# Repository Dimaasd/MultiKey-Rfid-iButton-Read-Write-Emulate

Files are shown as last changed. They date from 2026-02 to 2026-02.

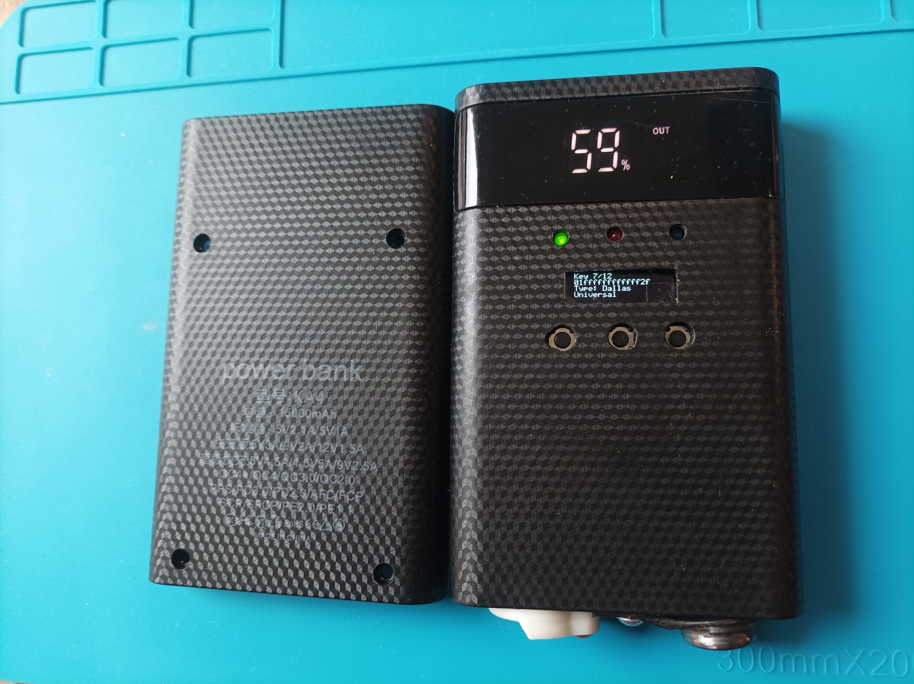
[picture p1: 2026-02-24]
jpg/IMG_20260224_112338.jpg

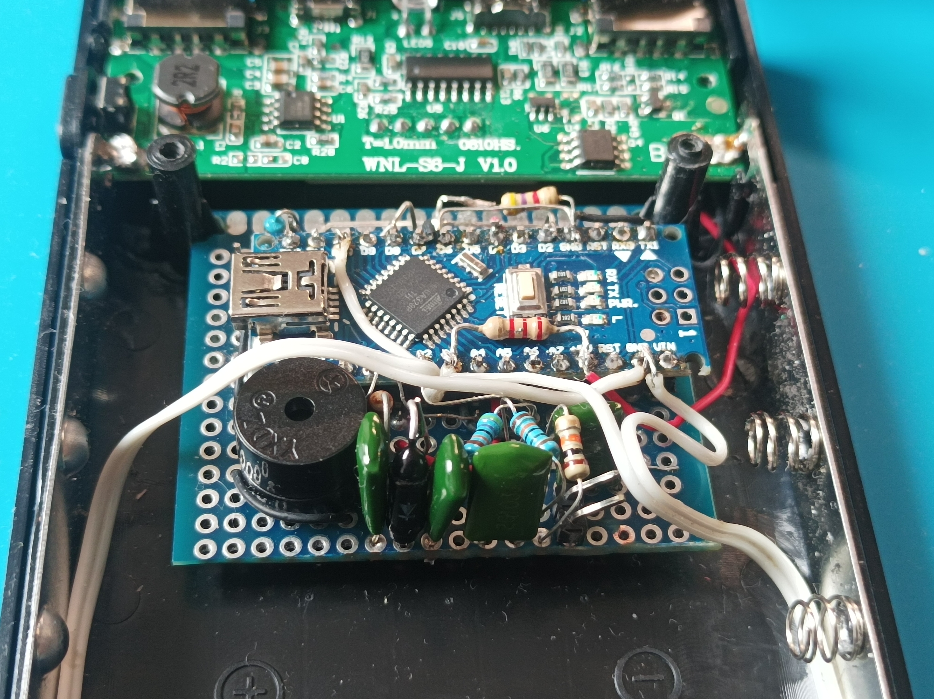
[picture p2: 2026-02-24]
jpg/IMG_20260224_112535.jpg

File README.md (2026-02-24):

# MultiKey-Rfid-iButton-Read-Write-Emulate

Пристрій призначений для читання, копіювання, збереження та емуляції ключів домофонів різних типів.

Він підтримує як контактні ключі Dallas (iButton), так і безконтактні RFID-мітки стандарту EM-Marine 125 кгц

Початковий скетч - це робота [AlexMalov/EasyKeyDublicatorRFID_OLED](https://github.com/AlexMalov/EasyKeyDublicatorRFID_OLED) (т.н. проект "MEXATРОН DIY")
- змінені деякі елементи схеми і коду (запущена емуляція iButton)
- замість енкодера, три кнопки
- видалено виведення інформації в серійний порт (для економії місця в пам'яті в ардуїно)
- дисплей: OLED 128x32 (I2C) хотів поміняти на - 128x64 (I2C), але пам'ять ардуіно обмежена - бібліотеки не влазять
- котушка L1 345 мкГн - замінена на 736 мкГн (провід 0,25 мм, 155 витків, діаметр 20 мм, ширина 2 мм, корпус котушки.stl)
- конденсатор для резенансу С1 4.7нФ - замінений на 2,2нФ
  
Основна проблема добитись резонансу в контурі, 
потріно намотати на котушку більше витків (180 наприклад),
а потім в режимі зчитування (горить зелений діод) замірювати напругу на контрольних точках TP1 і TP2,
відмотуючи по одному витку з котушки контролюємо зміну напруги, 
при досягненні найвищої напруги - фіксуємо край проводу,
У мене зчитує. записує, емулює з 5-6 сантиметрів,
корпус котушки перед 3Д друком розрізав у слайсері на три частини- два борти і центр,
а потім склеював усе разом, борти з гладкою стороною зазташовував в середину, 
щоб при намотці провід не зачипався об зазубрини погрішностей друку,
Використав корпус павербанку, по назві можна знайти на аліекспресі або де інде, 
макетна плата помістилась замість двох акумуляторів 18650, зручно із живлення не подрібно додаткового вимикача,
одне натискання на бокову кнопку павербанку включає плату і заодно подається напруга 5 вольт на ардуіно нано,
сама плата павербанку не переходить в сон від низького зпоживання,
виключається подвійним натисканням на цю ж кнопку.
задня кришка закручується гвинтами.

4x18650 DIY Power Bank Shell 25W Super Fast Charging Case Dual USB Micro Type C Battery Storage Box Case Holder Without Battery

Schematic

🔧 Апаратна частина:

Мікроконтролер: Arduino Nano (ATmega328P),
- Дисплей: OLED 128x32 (I2C)
- Інтерфейс керування: 3 тактові кнопки
- Індикація: RGB-світлодіод + окремий світлодіод
- Звуковий супровід: п'єзодинамік
- Живлення: від USB або зовнішнього джерела

📌 Призначення виводів (Pinout):
- Пін	 - Призначення	   - Опис
- A3	 - iButtonPin	     - Лінія даних iButton
- 7	   - RfidPin	       - Лінія даних Rfid
- 10   - iBtnEmulPin	   - Емуляція iButton
- 8	- R_Led	RGB - червоний
- 2	- G_Led	RGB -  зелений
- 12 - B_Led RGB - синій
- 6	- ACpin	- Вхід аналогового компаратора, замкнутий на gnd
- 3	- speakerPin	- Buzzer П'єзодинамік
- 11	- FreqGen	- Генератор 125 кГц для RFID
- A1	- BTN_MODE	- Кнопка режиму
- A2	- BTN_LEFT	- Кнопка "Лівий"
- A0	- BTN_RIGHT	- Кнопка "Правий"
  
📦 Пам'ять та зберігання:
- EEPROM: зберігає до 42 ключів з назвами

Кожен ключ зберігається як структура KeyData:
- 8 байт - ID ключа
- 16 байт - текстова назва

🗝️ Підтримувані типи ключів:
- Dallas (iButton) - контактні ключі
- Cyfral - контактні
- Metacom - контактні
- TM2004 - контактні
- EM-Marine - безконтактні (RFID 125 кГц)

🎮 Режими роботи (перемикання кнопкою MODE):
- Read (зелений) - режим читання ключів
- Write (червоний) - режим запису на чистий ключ
- BlueMode (синій) - режим емуляції ключа

🕹️ Керування:
- Дія	- Функція
- MODE (коротке натискання)	- Перемикання режимів (Read → Write → BlueMode)
- LEFT/RIGHT	- Перегортання збережених ключів
- MODE (утримання в Read) - 	Збереження поточного ключа в EEPROM
- MODE (утримання в Write) - 	Видалення поточного ключа (з підтвердженням)
- MODE (під час емуляції)	- Зупинка емуляції

🔄 Функціональні можливості:
- Читання ключів
- Автоматичне визначення типу ключа (Dallas, Cyfral, Metacom, EM-Marine) при піднесенні до зчитувача.

- Запис ключів:
- Підтримка різних типів чистих заготовок:
- TM2004
- RW1990-1 / RW1990-2
- TM01
- T5557 (для RFID)

- Емуляція ключів:
- Dallas: використовує бібліотеку OneWireHub для точної емуляції
- EM-Marine: генерація сигналу 125 кГц

- Керування пам'яттю:
- Збереження прочитаних ключів
- Видалення окремих ключів
- Перегляд списку ключів

- Автоматичне визначення дублікатів

🔊 Звукова індикація:
- Старт пристрою - мелодія
- Успішне читання/запис - звуковий сигнал
- Помилка - тривожний сигнал
- Початок/кінець емуляції - спеціальний сигнал
- Видалення ключа - низький звук

💡 Світлодіодна індикація:
- Зелений - режим читання
- Червоний - режим запису
- Синій - режим емуляції RFID-мітки
- Блимання синім - активна емуляція iButton

📟 Дисплей (OLED 128x32) Відображає:
- Поточний режим
- Номер ключа та загальну кількість
- HEX-код ключа (8 байт)
- Тип ключа
- Назву ключа (якщо є)
- Підказки для користувача

📚 Вбудовані універсальні ключі
- Пристрій містить набір універсальних ключів:
- Домофон
- Гараж
- UK-3 Cyfral
- Universal
- Vizit 99%
- Forward
- Cyfral
- Metakom 95%

🛠️ Використані бібліотеки:
- OneWire - робота з шиною 1-Wire
- OneWireSlave - емуляція пристроїв 1-Wire
- OneWireHub - розширена емуляція
- DS2401 - віртуальний пристрій Dallas
- GyverOLED - робота з OLED дисплеєм
- TimerOne - таймер для генерації сигналів
- pitches.h - ноти для звукових сигналів
- EEPROM - робота з внутрішньою пам'яттю

⚙️ Технічні деталі:
- Частота генератора RFID: 125 кГц
- Максимальна кількість ключів: 42
- Антидребезг кнопок: 50 мс
- Таймаут утримання: 1 секунда
- Автоматичне завершення емуляції: 30 секунд

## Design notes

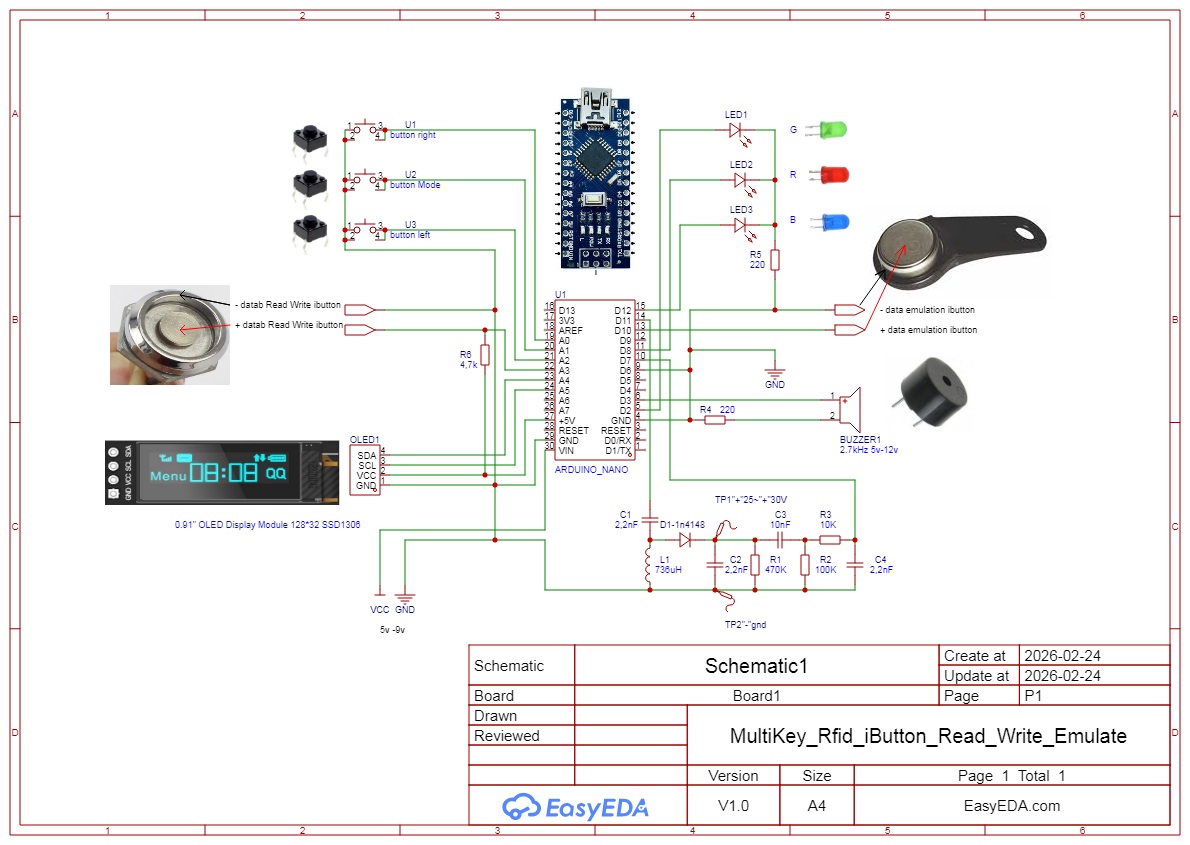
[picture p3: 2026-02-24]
Schematic.jpg

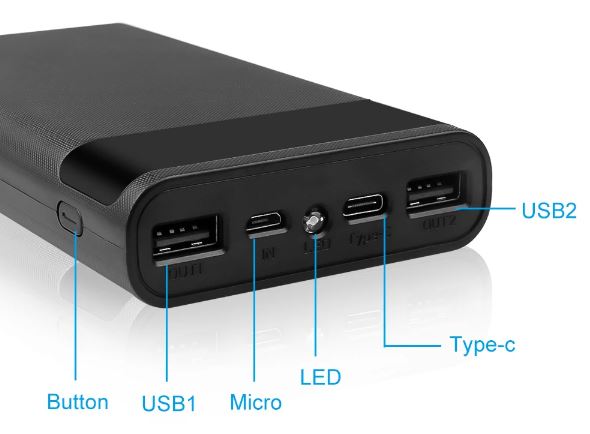
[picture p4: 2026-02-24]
jpg/Box.JPG

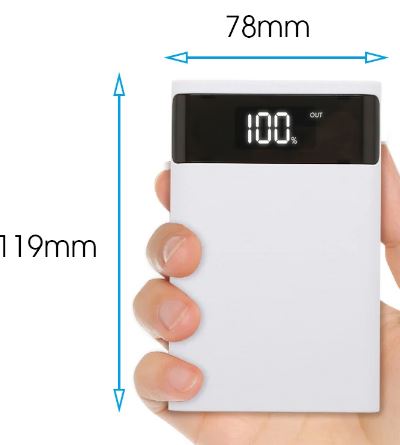
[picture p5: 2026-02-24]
jpg/Box2.JPG

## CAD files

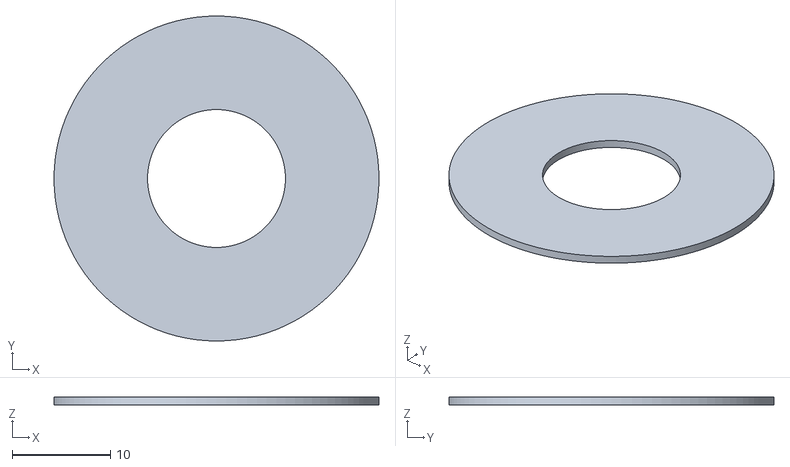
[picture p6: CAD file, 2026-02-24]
stl/борт котушки.stl
33.0 x 33.0 x 0.8

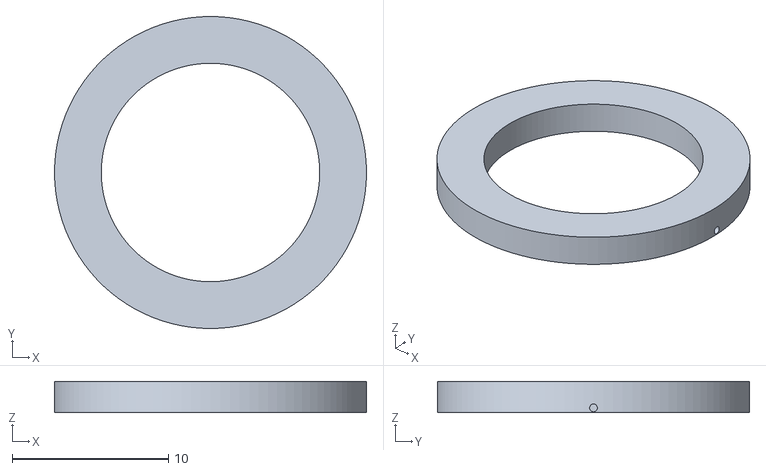
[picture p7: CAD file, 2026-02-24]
stl/центр котушки.stl
20.0 x 20.0 x 2.00

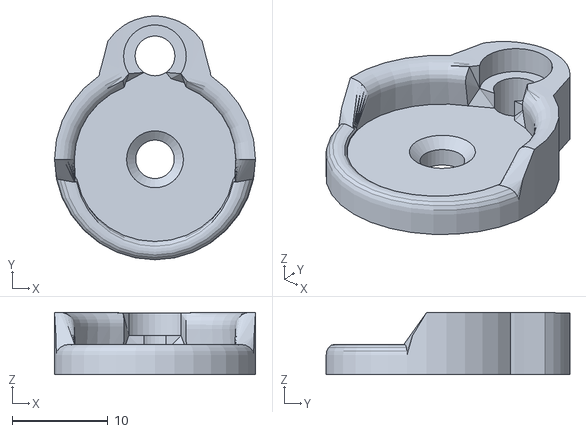
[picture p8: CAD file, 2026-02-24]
stl/ibutton_v1.stl
21.0 x 25.5 x 6.51

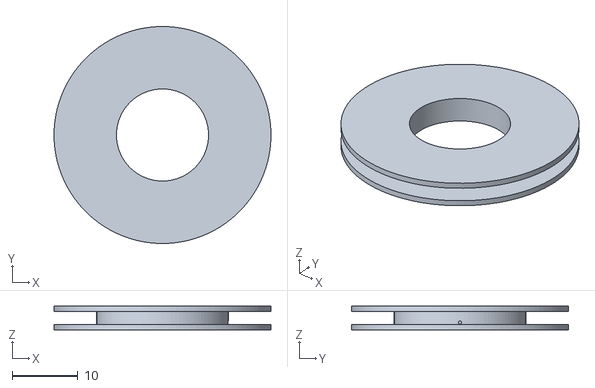
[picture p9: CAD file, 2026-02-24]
stl/корпус котушки.stl
33.0 x 33.0 x 3.60

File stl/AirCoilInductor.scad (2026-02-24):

//this is to build a straight open air coil inductor.

/* [Size] */

diameter = 20;
length = 2.0;
thickness = 3;
segments = 100;

/* [Lip] */

lip_width = 0.8;
lip_offset = 6.5;

/* [Holes] */

hole_upper = "no"; //[yes, no]
hole_lower = "yes"; //[yes, no]
hole_diameter = 0.5;

/* [Hidden] */

$fn = segments;

//build
difference() {
	OuterCoil();
    InnerCoil();
    
    if(hole_upper == "yes") {
        Hole([0, 0, lip_width + length+1 ]);
    }
    
    if(hole_lower == "yes") {
        Hole([0, 0, lip_width+0.3]);
    }
}

//modules
module OuterCoil() {
	union() {
		//base lip
		cylinder (
			h = lip_width, 
			d = lip_offset * 2 + diameter,
			center = false);

		translate ([0, 0, lip_width]) {
			//coil holder
			cylinder (
				h = length, 
				d = diameter,
				center = false);

			translate ([0, 0, length]) {
				//top lip
				cylinder (
					h = lip_width, 
					d = lip_offset * 2 + diameter,
					center = false);
			}	
		}
	}
}

module InnerCoil() {
    translate ([0, 0, -1]) {
        cylinder (
        h = lip_width * 2 + length + 2, 
        d = diameter - thickness * 2,
        center = false);
    }
}

module Hole(pos=[0, 0, 0]) {
    translate(pos) {
        rotate([0, 90, 0]) {
            cylinder (
                h = lip_width * 2 + diameter, 
                d = hole_diameter,
                center = false);
        }
    }
}

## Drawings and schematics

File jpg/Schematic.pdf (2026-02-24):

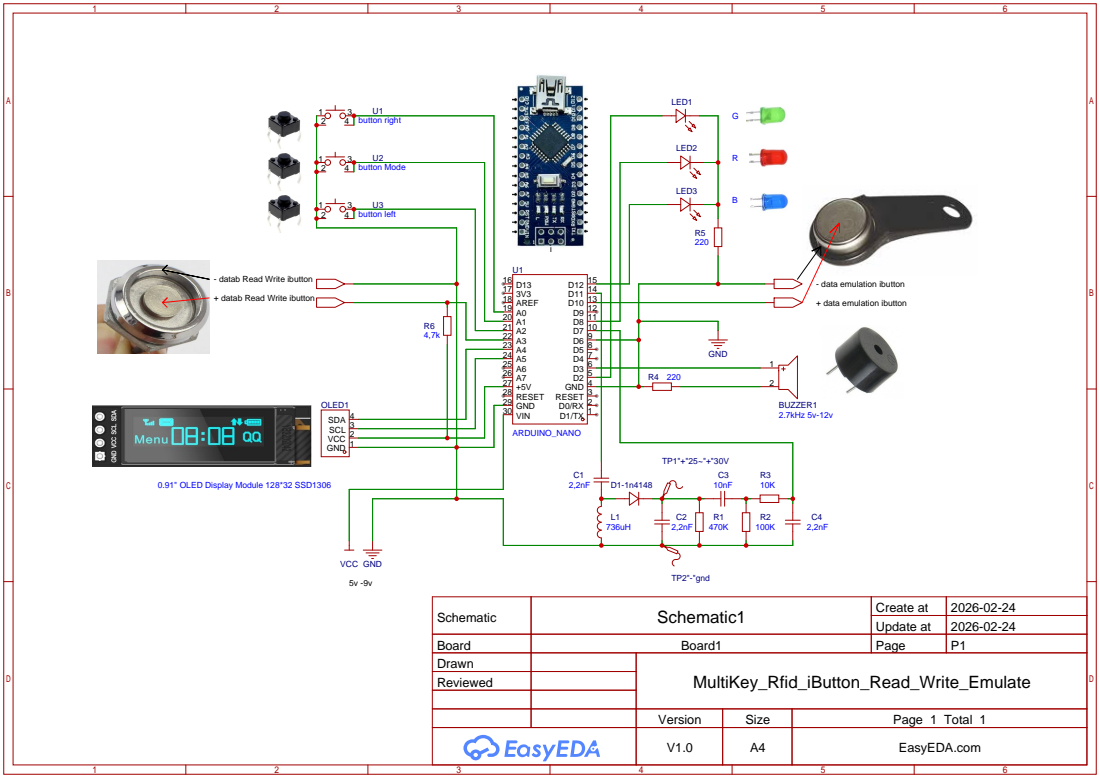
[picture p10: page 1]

+ datab Read Write ibutton

Schematic | Schematic1 | Create at | 2026-02-24

Update at | 2026-02-24

Board | Board1 | Page | P1
Drawn | | MultiKey_Rfid_iButton_Read_Write_Emulate
Reviewed

Version | Size | Page 1 Total 1
V1.0 | A4 | EasyEDA.com

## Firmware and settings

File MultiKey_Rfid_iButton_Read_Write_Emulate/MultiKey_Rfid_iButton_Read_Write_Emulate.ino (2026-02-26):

/*
  Sketch for "MultiKey-Rfid-iButton-Read-Write-Emulate"
  RFID Key Copier with OLED display and 42 keys storage in EEPROM
  Hardware based on Arduino Nano
  v 3.2 fix cyfral bug
  v 3.3 added RFID output in format FF:A9:8A:A1:81:D6:5E:8C: ( id 86 key 1513154234) Type: EM-Marine
  v 3.4 replaced encoder with three buttons control
  v 3.5 Simplified key adding - now keys are added through array with names
  v 3.6 Removed Luse_Led and all Serial outputs except e command for clearing
  v 3.7 Key name displayed in 4th line, key info in EEPROM - in first line
  v 4.0 Added iButton and RFID emulation
  v 4.1 Added key deletion via MODE + LEFT
*/

// Settings
#include <OneWire.h>
#include <OneWireSlave.h>
#include <OneWireHub.h>     // Added for iButton emulation
#include <DS2401.h>         // Added for Dallas emulation
#include "pitches.h"
#include <EEPROM.h>
#include "TimerOne.h"
#include "GyverOLED.h"

//settings
#define rfidUsePWD 0        // key uses password for change
#define rfidPWD 123456      // key password
#define rfidBitRate 2       // RFID exchange speed in kbps

//pins
#define iButtonPin A3      // ibutton data line
#define iBtnEmulPin 10     // emulator ibutton line
#define R_Led 8            // RGB Led
#define G_Led 2
#define B_Led 12
#define ACpin 6            // Input Ain0 of analog comparator 0.1V for EM-Marie 
#define speakerPin 3       // Speaker, buzzer, beeper
#define FreqGen 11         // 125 kHz generator
#define BTN_MODE A1         // Mode switch button read/write
#define BTN_LEFT A2         // "Left" button (previous key)
#define BTN_RIGHT A0       // "Right" button (next key)

OneWire ibutton (iButtonPin);
OneWireSlave iBtnEmul(iBtnEmulPin);       // iButton emulator for BlueMode

// ============ FOR EMULATION ============
auto hub = OneWireHub(iBtnEmulPin);      // Main OneWire hub for iButton emulation
DS2401* currentDS = nullptr;              // Current device for Dallas emulation
bool emulating = false;                   // Is emulation active
// =====================================

byte maxKeyCount;                         // maximum number of keys that fit in EEPROM, but not > 42
byte EEPROM_key_count;                    // number of keys 0..maxKeyCount stored in EEPROM
byte EEPROM_key_index = 0;                // 1..EEPROM_key_count number of the last key written to EEPROM  
byte addr[8];                             // temporary buffer
byte keyID[8];                            // key ID for writing
byte rfidData[5];                         // significant frid em-marine data
byte halfT;                               // half period for metacom

// Button processing variables
unsigned long lastDebounceTime[3] = {0, 0, 0};
unsigned long debounceDelay = 50;
unsigned long holdTimeStart = 0;
unsigned long comboTimeStart = 0;          // Combination start time
bool holdMode = false;
bool comboMode = false;                    // Combination waiting mode
bool lastBtnState[3] = {HIGH, HIGH, HIGH};
bool btnState[3] = {HIGH, HIGH, HIGH};

// ============ SIMPLIFIED KEY ADDING ============
// Structure for storing key with name
struct UniversalKey {
  const char* name;        // Key name for OLED display
  byte data[8];            // Key data
};

  // Array of universal keys with names
UniversalKey universalKeys[] = {
  // Dallas/Metakom/Cyfral keys (start with 0x01)
  {"Univer 1F",              {0x01, 0xFF, 0xFF, 0xFF, 0xFF, 0x1F, 0xFF, 0x00}}, // - 1 Univer 1F
  {"Univer 2F",              {0x01, 0xFF, 0xFF, 0xFF, 0xFF, 0x2F, 0xFF, 0x00}}, // - 2 Univer 2F
//  {"UK-1 Metakom 2003",      {0x01, 0xFF, 0xFF, 0xFF, 0xFF, 0x00, 0x00, 0x9B}}, // - 3 UK-1 Metakom 2003
//  {"UK-2 Vizit",             {0x01, 0xBE, 0x40, 0x11, 0x5A, 0x36, 0x00, 0xE1}}, // - 4 UK-2 Vizit
//  {"UK-3 Cyfral",            {0x01, 0x00, 0x00, 0x00, 0x00, 0x00, 0x00, 0x3D}}, // - 5 UK-3 Cyfral
//  {"Standard Universal",     {0x01, 0xFF, 0xFF, 0xFF, 0xFF, 0xFF, 0xFF, 0x2F}}, // - 6 Standard universal key
//  {"Ordinary",               {0x01, 0xFF, 0xFF, 0xFF, 0xFF, 0xFF, 0xFF, 0x00}}, // - 7 Ordinary
//  {"Old Door Work",          {0x01, 0x00, 0x00, 0x00, 0x00, 0x90, 0x19, 0xFF}}, // - 8 Works great on old intercoms
//  {"Cyfral Metakom 1",       {0x01, 0x53, 0xD4, 0xFE, 0x00, 0x00, 0x7E, 0x88}}, // - 9 Cyfral, Metakom
//  {"Cyfral Metakom 2",       {0x01, 0x53, 0xD4, 0xFE, 0x00, 0x00, 0x7E, 0x00}}, // - 10 Cyfral, Metakom
  {"Metakom 98%",            {0xFF, 0xFF, 0xFF, 0xFF, 0xFF, 0xFF, 0xFF, 0x14}}, // - 11 Opens 98% Metakom and some Cyfral
//  {"Cyfral Filter",          {0x01, 0xFF, 0xFF, 0x01, 0x00, 0x00, 0x00, 0x00}}, // - 12 Cyfral intercoms + filter and protection
//  {"Metakom",                {0x01, 0xFF, 0xFF, 0xFF, 0xFF, 0x00, 0x00, 0x00}}, // - 13 Metakom
  {"Metakom 95%",            {0xFF, 0xFF, 0xFF, 0xFF, 0xFF, 0x00, 0x00, 0xA0}}, // - 14 Metakom 95%
//  {"KeyMan",                 {0x01, 0x00, 0xBE, 0x11, 0xAA, 0x00, 0x00, 0xFB}}, // - 15 KeyMan intercoms
//  {"Vizit KeyMan",           {0x01, 0xBE, 0x40, 0x11, 0x0A, 0x00, 0x00, 0x1D}}, // - 16 tested works Vizit sometimes KeyMan
//  {"Vizit 99%",              {0x01, 0x53, 0xD4, 0xFE, 0x00, 0x00, 0x00, 0x6F}}, // - 17 Vizit intercoms - up to 99%
//  {"Vizit 99% Plus",         {0x01, 0xBE, 0x40, 0x11, 0x5A, 0x36, 0x00, 0x00}}, // - 18 Vizit 99%
//  {"Forward",                {0x01, 0x76, 0xB8, 0x2E, 0x0F, 0x00, 0x00, 0x5C}}, // - 19 Forward intercoms
//  {"Eltis 90%",              {0x01, 0xA9, 0xE4, 0x3C, 0x09, 0x00, 0x00, 0x00}}, // - 20 Eltis intercoms - up to 90%
//  {"Vizit Tested 1",         {0x01, 0xBE, 0x40, 0x11, 0x5A, 0x56, 0x00, 0xBB}}, // - 21 tested works
//  {"Vizit Tested 2",         {0x01, 0xBE, 0x40, 0x11, 0x00, 0x00, 0x00, 0x77}}, // - 22 tested works
  {"Metakom 22",             {0x01, 0xAA, 0x69, 0xC9, 0x36, 0x00, 0x00, 0xE9}}, // Your original Metakom key
//  {"EM-Marine 76",           {0xFF, 0xA9, 0x8A, 0xB8, 0x13, 0x14, 0x8F, 0xB4}}, // - EM-Marine 76
//  {"EM-Marine 42a",          {0xFF, 0xA9, 0x8A, 0xA7, 0x65, 0xBC, 0x16, 0xE6}}, // - EM-Marine 42a
//  {"EM-Marine 42b",          {0xFF, 0xA9, 0x8A, 0xA7, 0x65, 0xB9, 0x3D, 0x9C}}, // - EM-Marine 42b
  {"Garage EM-Marine",       {0xFF, 0x94, 0x60, 0x05, 0xF7, 0xBF, 0x5D, 0x30}}  // Your original Garage EM-Marine key
};

// Number of keys in array
const int UNIVERSAL_KEYS_COUNT = sizeof(universalKeys) / sizeof(UniversalKey);
// ==================================================

enum emRWType {rwUnknown, TM01, RW1990_1, RW1990_2, TM2004, T5557, EM4305};               // blank type
enum emkeyType {keyUnknown, keyDallas, keyTM2004, keyCyfral, keyMetacom, keyEM_Marine};    // original key type  
emkeyType keyType;
enum emMode {md_empty, md_read, md_write, md_blueMode};               // copier operating mode
emMode copierMode = md_empty;

GyverOLED<SSD1306_128x32, OLED_NO_BUFFER> oled; // Using without buffer

//***************** sounds ****************
void Sd_StartOK() {   // sound "Successful startup"
  tone(speakerPin, NOTE_A7); delay(100);
  tone(speakerPin, NOTE_G7); delay(100);
  tone(speakerPin, NOTE_E7); delay(100); 
  tone(speakerPin, NOTE_C7); delay(100);  
  tone(speakerPin, NOTE_D7); delay(100); 
  tone(speakerPin, NOTE_B7); delay(100); 
  tone(speakerPin, NOTE_F7); delay(100); 
  tone(speakerPin, NOTE_C7); delay(100);
  noTone(speakerPin); 
}

void Sd_ReadOK() {  // sound OK
  for (int i=400; i<6000; i=i*1.5) { tone(speakerPin, i); delay(20); }
  noTone(speakerPin);
}

void Sd_WriteStep(){  // sound "next step"
  for (int i=2500; i<6000; i=i*1.5) { tone(speakerPin, i); delay(10); }
  noTone(speakerPin);
}

void Sd_ErrorBeep() {  // sound "ERROR"
  for (int j=0; j <3; j++){
    for (int i=1000; i<2000; i=i*1.1) { tone(speakerPin, i); delay(10); }
    delay(50);
    for (int i=1000; i>500; i=i*1.9) { tone(speakerPin, i); delay(10); }
    delay(50);
  }
  noTone(speakerPin);
}

void Sd_DeleteOK() {  // sound "Deletion successful"
  tone(speakerPin, NOTE_C7); delay(100);
  tone(speakerPin, NOTE_E7); delay(100);
  tone(speakerPin, NOTE_G7); delay(100);
  tone(speakerPin, NOTE_C8); delay(200);
  noTone(speakerPin);
}

void Sd_ComboStart() { // sound "Combination activated"
  tone(speakerPin, NOTE_C7); delay(50);
  tone(speakerPin, NOTE_E7); delay(50);
  tone(speakerPin, NOTE_G7); delay(50);
  noTone(speakerPin);
}

// Function to get key name (if exists)
String getKeyName(byte buf[8]) {
  for (int i = 0; i < UNIVERSAL_KEYS_COUNT; i++) {
    bool match = true;
    for (int j = 0; j < 8; j++) {
      if (universalKeys[i].data[j] != buf[j]) {
        match = false;
        break;
      }
    }
    if (match) {
      return String(universalKeys[i].name);
    }
  }
  return "";
}

// Function for displaying RFID information - 4 lines
void OLED_printRFIDInfo(byte buf[8], byte msgType = 0) {
  oled.clear();
  oled.home();
  
  // First line - key info in EEPROM
  String st1 = "";
  switch (msgType){
    case 0: st1 = "Key " + String(EEPROM_key_index) + " of " + String(EEPROM_key_count) + " in Memory"; break;      
    case 1: st1 = "Hold to save";  break; 
    case 3: st1 = "Key " + String(indxKeyInROM(buf)) + " exists in Memory";  break;
    case 4: st1 = "Delete key?"; break;
    case 5: st1 = "Key deleted!"; break;
  }
  oled.println(st1);
  
  // Second line - HEX values with colon
  String st2 = "";
  for (byte i = 0; i < 8; i++) {
    if (buf[i] < 0x10) st2 += "0";
    st2 += String(buf[i], HEX);
    if (i < 7) st2 += "";
  }
  oled.println(st2);
  
  // Third line - id and key
  String st3 = "";
  if (vertEvenCheck(buf)) {
    unsigned long keyNum = (unsigned long)rfidData[1]<<24 | (unsigned long)rfidData[2]<<16 | 
                           (unsigned long)rfidData[3]<<8 | (unsigned long)rfidData[4];
    st3 = "id " + String(rfidData[0]) + " key " + String(keyNum);
  } else {
    st3 = "(id ? key ?)";
  }
  oled.println(st3);
  
  // Fourth line - key name (if exists) or key type
  String st4 = "";
  String keyName = getKeyName(buf);
  if (keyName.length() > 0) {
    st4 = keyName;
  } else {
    st4 = "Type: ";
    switch (keyType){
      case keyDallas: st4 += "Dallas"; break;      
      case keyCyfral: st4 += "Cyfral"; break;  
      case keyMetacom: st4 += "Metakom"; break;             
      case keyEM_Marine: st4 += "EM-Marine"; break;
      case keyTM2004: st4 += "TM2004"; break;
      case keyUnknown: st4 += "Unknown"; break;
    }
  }
  oled.println(st4);
  
  oled.update();
}

// Function for displaying regular keys - 4 lines
void OLED_printKey(byte buf[8], byte msgType = 0){
  // For RFID keys use special format
  if (keyType == keyEM_Marine) {
    OLED_printRFIDInfo(buf, msgType);
    return;
  }
  
  oled.clear();
  oled.home();
  
  // First line - key info in EEPROM
  String st1 = "";
  switch (msgType){
    case 0: st1 = "Key " + String(EEPROM_key_index) + " of " + String(EEPROM_key_count) + " in Memory"; break;      
    case 1: st1 = "Hold to save";  break; 
    case 3: st1 = "Key " + String(indxKeyInROM(buf)) + " exists in Memory";  break;
    case 4: st1 = "Delete key?"; break;
    case 5: st1 = "Key deleted!"; break;
  }
  oled.println(st1);
  
  // Second line - HEX values with colon
  String st2 = "";
  for (byte i = 0; i < 8; i++) {
    if (buf[i] < 0x10) st2 += "0";
    st2 += String(buf[i], HEX);
    if (i < 7) st2 += "";
  }
  oled.println(st2);
  
  // Third line - empty (for alignment) or key type
  String st3 = "";
  st3 = "Type: ";
  switch (keyType){
    case keyDallas: st3 += "Dallas"; break;      
    case keyCyfral: st3 += "Cyfral"; break;  
    case keyMetacom: st3 += "Metakom"; break;             
    case keyTM2004: st3 += "TM2004"; break;
    case keyUnknown: st3 += "Unknown"; break;
  }
  oled.println(st3);
  
  // Fourth line - key name (if exists)
  String st4 = getKeyName(buf);
  oled.println(st4);
  
  oled.update();
}

void OLED_printError(String st, bool err = true){
  oled.clear();
  oled.home();
  if (err) oled.println("Error!");
    else oled.println("OK");
  oled.println(st);  
  oled.update();
}

// Function to add all universal keys
void addAllUniversalKeys() {
  for (int i = 0; i < UNIVERSAL_KEYS_COUNT; i++) {
    if (EPPROM_AddKey(universalKeys[i].data)) {
      oled.clear();
      oled.home();
      oled.println("Key added:");
      oled.println(String(universalKeys[i].name));
      oled.update();
      Sd_ReadOK();
      delay(1000);
    }
  }
}

// ============ KEY DELETION FUNCTION ============
void deleteCurrentKey() {
  if (EEPROM_key_count == 0) {
    OLED_printError("No keys");
    Sd_ErrorBeep();
    delay(1000);
    return;
  }
  
  // Show confirmation
  OLED_printKey(keyID, 4);
  
  // Wait 2 seconds for confirmation
  unsigned long confirmStart = millis();
  bool confirmed = false;
  
  while (millis() - confirmStart < 2000) {
    // If MODE button pressed again - confirm deletion
    if (digitalRead(BTN_MODE) == LOW) {
      delay(50);
      if (digitalRead(BTN_MODE) == LOW) {
        confirmed = true;
        break;
      }
    }
    delay(10);
  }
  
  if (confirmed) {
    // Delete current key
    byte buf1[8];
    
    // Shift all keys after current one back by one position
    for (byte j = EEPROM_key_index; j < EEPROM_key_count; j++) {
      EEPROM.get((j + 1) * sizeof(buf1), buf1);
      EEPROM.put(j * sizeof(buf1), buf1);
    }
    
    // Decrease key counter
    EEPROM_key_count--;
    EEPROM.update(0, EEPROM_key_count);
    
    // Adjust index
    if (EEPROM_key_index > EEPROM_key_count) {
      EEPROM_key_index = EEPROM_key_count;
    }
    if (EEPROM_key_index < 1 && EEPROM_key_count > 0) {
      EEPROM_key_index = 1;
    }
    EEPROM.update(1, EEPROM_key_index);
    
    // Update current key
    if (EEPROM_key_count > 0) {
      EEPROM_get_key(EEPROM_key_index, keyID);
    }
    
    // Show result
    OLED_printKey(keyID, 5);
    Sd_DeleteOK();
    delay(1500);
    
    // Return to normal display
    if (EEPROM_key_count > 0) {
      OLED_printKey(keyID);
    } else {
      oled.clear();
      oled.home();
      oled.println("Memory empty");
      oled.update();
    }
  } else {
    // Cancel deletion
    OLED_printKey(keyID);
  }
}
// ==================================================

// ============ EMULATION FUNCTIONS ============

// CRC8 for iButton
uint8_t onewire_crc8(const uint8_t *addr, uint8_t len) {
  uint8_t crc = 0;
  while (len--) {
    uint8_t inbyte = *addr++;
    for (uint8_t i = 8; i; i--) {
      uint8_t mix = (crc ^ inbyte) & 0x01;
      crc >>= 1;
      if (mix) crc ^= 0x8C;
      inbyte >>= 1;
    }
  }
  return crc;
}

// Start iButton emulation (Dallas, Cyfral, Metakom)
void startIButtonEmulation() {
  // Remove previous device if existed
  if (currentDS != nullptr) {
    hub.detach(*currentDS);
    delete currentDS;
    currentDS = nullptr;
  }
  
  // Fix CRC for Dallas keys
  byte emulKey[8];
  memcpy(emulKey, keyID, 8);
  
  if (keyType == keyDallas || keyType == keyTM2004) { // Dallas key
    emulKey[7] = onewire_crc8(emulKey, 7);
  }
  
  // For Cyfral and Metakom - emulate as Dallas with correct first byte
  if (keyType == keyCyfral) {
    emulKey[0] = 0x01; // Pretend it's Dallas
    emulKey[7] = onewire_crc8(emulKey, 7);
  }
  if (keyType == keyMetacom) {
    emulKey[0] = 0x01; // Pretend it's Dallas
    emulKey[7] = onewire_crc8(emulKey, 7);
  }
  
  // Create new device
  currentDS = new DS2401(emulKey[0], emulKey[1], emulKey[2], emulKey[3], 
                         emulKey[4], emulKey[5], emulKey[6]);
  
  hub.attach(*currentDS);  // Connect to hub
  
  // Show on display
  oled.clear();
  oled.home();
  oled.println(">> iButton Emulation <");
  oled.println("Key:");
  
  char buf[20];
  sprintf(buf, "%02X %02X %02X %02X", emulKey[0], emulKey[1], emulKey[2], emulKey[3]);
  oled.println(buf);
  sprintf(buf, "%02X %02X %02X %02X", emulKey[4], emulKey[5], emulKey[6], emulKey[7]);
  oled.println(buf);
  oled.println("MODE=stop");
  oled.update();
  
  emulating = true;
  digitalWrite(B_Led, HIGH); // Blue LED - emulation mode
}
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
void loop() {
  char echo = Serial.read();
  
  // Only e command for memory clearing remains
  if (echo == 'e'){
    oled.clear();
    oled.home();
    oled.println("Memory cleared successfully!");
    EEPROM.update(0, 0); EEPROM.update(1, 0);
    EEPROM_key_count = 0; EEPROM_key_index = 0;
    Sd_ReadOK();
    oled.update();
  }
  
  // Reading buttons
  bool modeBtn = readButton(BTN_MODE, 0);
  bool leftBtn = readButton(BTN_LEFT, 1);
  bool rightBtn = readButton(BTN_RIGHT, 2);
  
  // ===== MODE PROCESSING =====
  if (!emulating) {
    // Normal mode (not emulation)
    
    // ===== MODE + LEFT COMBINATION PROCESSING (DELETION) =====
    if (modeBtn == LOW && leftBtn == LOW) {
      if (!comboMode) {
        comboTimeStart = millis();
        comboMode = true;
        Sd_ComboStart(); // Sound signal for combination start
      } else if (millis() - comboTimeStart > 1000) { // Hold for 1 second
        if (digitalRead(BTN_MODE) == LOW && digitalRead(BTN_LEFT) == LOW) {
          deleteCurrentKey();
          while (digitalRead(BTN_MODE) == LOW || digitalRead(BTN_LEFT) == LOW); // Wait for release
        }
        comboMode = false;
      }
    } else {
      comboMode = false;
    }
    
    // MODE button processing (mode switching) - only if not in combination
    static bool lastModeBtnState = HIGH;
    if (modeBtn == LOW && lastModeBtnState == HIGH && !comboMode) {
      delay(50); // additional debounce
      if (digitalRead(BTN_MODE) == LOW && !comboMode) {
        switch (copierMode){
          case md_empty: Sd_ErrorBeep(); break;
          case md_read: 
            copierMode = md_write; 
            clearLed(); 
            digitalWrite(R_Led, HIGH);  
            break;
          case md_write: 
            copierMode = md_blueMode; 
            clearLed(); 
            // In md_blueMode start appropriate emulation
            if (keyType == keyEM_Marine) {
              startRFIDEmulation();
            } else {
              startIButtonEmulation();
            }
            break;
          case md_blueMode: 
            copierMode = md_read; 
            clearLed(); 
            digitalWrite(G_Led, HIGH); 
            break;
        }
        if (copierMode != md_blueMode) {
          OLED_printKey(keyID);
          Sd_WriteStep();
        }
      }
    }
    lastModeBtnState = modeBtn;
    
    // LEFT button processing (previous key) - only if not in combination
    static bool lastLeftBtnState = HIGH;
    if (leftBtn == LOW && lastLeftBtnState == HIGH && EEPROM_key_count > 0 && copierMode != md_blueMode && !comboMode) {
      delay(50);
      if (digitalRead(BTN_LEFT) == LOW && !comboMode) {
        EEPROM_key_index--;
        if (EEPROM_key_index < 1) EEPROM_key_index = EEPROM_key_count;
        EEPROM_get_key(EEPROM_key_index, keyID);
        OLED_printKey(keyID);
        Sd_WriteStep();
      }
    }
    lastLeftBtnState = leftBtn;
    
    // RIGHT button processing (next key)
    static bool lastRightBtnState = HIGH;
    if (rightBtn == LOW && lastRightBtnState == HIGH && EEPROM_key_count > 0 && copierMode != md_blueMode && !comboMode) {
      delay(50);
      if (digitalRead(BTN_RIGHT) == LOW) {
        EEPROM_key_index++;
        if (EEPROM_key_index > EEPROM_key_count) EEPROM_key_index = 1;
        EEPROM_get_key(EEPROM_key_index, keyID);
        OLED_printKey(keyID);
        Sd_WriteStep();
      }
    }
    lastRightBtnState = rightBtn;
    
    // MODE button hold processing (key saving) - only if not in combination
    if (copierMode != md_empty && modeBtn == LOW && copierMode != md_blueMode && !comboMode) {
      if (!holdMode) {
        holdTimeStart = millis();
        holdMode = true;
      } else if (millis() - holdTimeStart > 1000) { // Hold for 1 second
        if (digitalRead(BTN_MODE) == LOW && !comboMode) {
          if (EPPROM_AddKey(keyID)) {
            OLED_printError("Key saved", false);
            Sd_ReadOK();
            delay(1000); 
          } else {
            Sd_ErrorBeep();
          }
          OLED_printKey(keyID);
          while (digitalRead(BTN_MODE) == LOW); // Wait for release
        }
        holdMode = false;
      }
    } else {
      holdMode = false;
    }
    
    // Delay for stable operation
    if (millis() - stTimer < 100) return;
    stTimer = millis();
    
    // Main operation cycle depending on mode
    switch (copierMode){
      case md_empty: 
      case md_read: 
        if (searchCyfral() || searchMetacom() || searchEM_Marine() || searchIbutton() ) {
          Sd_ReadOK();
          copierMode = md_read;
          digitalWrite(G_Led, HIGH);
          if (indxKeyInROM(keyID) == 0) OLED_printKey(keyID, 1);
            else OLED_printKey(keyID, 3);
        } 
        break;
      case md_write:
        if (keyType == keyEM_Marine) write2rfid();
          else write2iBtn(); 
        break;
      case md_blueMode:
        // Already processed in emulation mode
        break;
    }
  } else {
    // ===== EMULATION MODE =====
    
    // MODE button - stop emulation
    static bool lastModeBtnState = HIGH;
    if (modeBtn == LOW && lastModeBtnState == HIGH) {
      delay(50);
      if (digitalRead(BTN_MODE) == LOW) {
        stopEmulation();
        copierMode = md_read;
        clearLed();
        digitalWrite(G_Led, HIGH);
        while (digitalRead(BTN_MODE) == LOW);
      }
    }
    lastModeBtnState = modeBtn;
    
    // Continue emulation depending on key type
    if (keyType == keyEM_Marine) {
      // For RFID - constantly send key
      sendRFIDKey(keyID);
    } else {
      // For iButton - process requests
      hub.poll();
    }
    
    // Blink blue LED
    digitalWrite(B_Led, (millis() / 500) % 2);
  }
  
  delay(1);
}
